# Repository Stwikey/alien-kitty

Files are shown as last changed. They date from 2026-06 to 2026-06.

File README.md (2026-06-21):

# Alien Cat

Screenshot 2026-06-15 at 9 47 17 AM

Have you ever wanted a cute little pet on your desk? Now you can with a cute little cat from outer space. You can pet it by pushing its head down and it'll purr using a vibration motor! Using a rotary encoder you can turn its head around, be careful you don't wanna turn a full 360 or else the cat might start to feel uncomfortable. It's eyes change when you pet it using an LCD.



# How its made
With a 16x2 LCD for its eyes, a vibration motor for purring, an arduino UNO R3 for the brains, and a rotary encoder to turn its head and act as a button. The rest is 3D printed, 4 screws to hold the LCD in place, everything else is either a snap connection or attached when printing. 

# How to use
Alien Cat is easy to use! Leave it on your desk and if you want you can pet it. It's to put simply a desk decoration. You can turn its head around, or press down on its head and it will respond! Twist its head too much and it might get dizzy, but if you pet it (push down) it'll become happy and start purring! 

# Why it was made?
Why not? We looked around and realized our desks are super messy, why not add more to the mess and have a little desk pet. The alien cat design was just a random idea! It was also a good excuse to use components that we haven't used before and to design something that looks cute. 

# Schematic 


# How to assemble
1. The star
   The star comes in two pieces, the "lid" and the star itself. The lid of the star is a thin piece of plastic that should go on the bottom (contrary to the name!). Place your Arduino UNO R3, and batteries on top and then place the star on top.

   Screenshot 2026-06-14 at 11 30 19 PM

   Screenshot 2026-06-14 at 11 28 06 PM

2. The body
   Here it gets a little more difficult! Place the vibration motor and rotary encoder in their respective spots on the top of the body. The vibration motor should fit in the cut out circle spot while the rotary encoder sits in the middle. Connect the wiring for the vibration motor and the rotary encoder by threading the wires through the body. Then you can connect them via the hole in the star and hole at the base of the cat!

   The body is in two pieces, you can put them together after assembling the electronics with adhesive! 

   Screenshot 2026-06-14 at 11 33 17 PM

4. The head
   Another tricky part! Screw in the LCD in the respective slot! The LCD should face outwards and pointing at the hollow holes in the cat face. The head is similar to the body and is in two pieces, you can put them together after assembling the electronics with adhesive! 

   Screenshot 2026-06-14 at 11 35 51 PM

   There is a slot at the base of the cat head to thread wires through. After you are done you can place the cat head direction on top of the rotary encoder.     At the bottom of the cat head there is a spot for it, align it with the grooves for a nice fit.

5. firmware

connect your device to the arduino through a USB cable and run the code on Arduino IDE!

once everything has been placed you now have a alien desktop kitty! push on its head to activate the rotary encoder switch for head pads, twist its head for it to change expressions on the lcd eyes and listen to it purr through the vibration motor
  
Optional steps:

Feel free to sand, prime, and paint the alien kitty. This doesn't serve any functional purpose and is purely cosmetic. 

# BOM 
| | Product Description | | Qty | Unit Price (CAD) | Total (CAD) | Product Link |
|---|---|---|-----|---|---|---|
| | Arduino Uno R3 | | 1 | 5.36 | 5.36 | https://www.aliexpress.com/item/1005009463538789.html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 |
| | LCD 16 x 2 | | 1 | 2.23 | 2.23 | https://www.aliexpress.com/item/1005011609490073.html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 |
| | AA 1.5V Battery | | 4 | 0.395 | 1.58 | https://www.aliexpress.com/item/1005011987720458.html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 |
| | 220 Ω Resistor | | 10  | 0.087 | 0.87 | https://www.aliexpress.com/item/1005007643210127.html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 |
| | 10 Ω Resistor | | 10  | 0.087 | 0.87 | https://www.aliexpress.com/item/1005007643210127.html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 |
| | Vibration Motor 10mm x 2mm | | 1 | 1.28 | 1.28 | https://www.aliexpress.com/item/1005006821274949.html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 |
| | Ec11 Rotary Encoder | | 2 | 2.305 | 4.61 | https://www.aliexpress.com/item/1005006056166298.html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 |
| | 1000 Ω Resistor | | 10  | 0.087 | 1.56 | https://www.aliexpress.com/item/1005007643210127.html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 |
| | NPN Transistor (PN2222) | | 50  | 0.0312 | 1.47 | https://www.aliexpress.com/item/1005009835608932.html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 |
| | Adhesive | | 1 | 0.96 | 0.96 | https://www.aliexpress.com/item/1005005081659956.html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 |
| | M3 Heat Inserts | | 50  | 0.0738 | 3.69 | https://www.aliexpress.com/item/1005008666672949.html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 |
| | Sandpaper | | 15  | 0.08066666667 | 1.21 | https://www.aliexpress.com/item/1005012104535956.html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 |
| | Paint | | 24  | 0.175 | 4.2 | https://www.aliexpress.com/item/1005005567785602.html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 |
| | Primer | | 1 | 17.26 | 17.26 | https://www.aliexpress.com/item/1005012483471322.html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 |
| | Top Coat | | 1 | 13.88 | 13.88 | https://www.amazon.ca/Rust-Oleum-Painters-Touch-Ultra-Semi-Gloss/dp/B081FMDXRY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 |
| | M3 x 3mm Screws | | 10  | 0.112 | 1.12 | https://www.moddiy.com/products/1271/M3.0-x-3mm-Black-Screws-CM3X3-5.0.html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 |
| | 3D Printing | | 1 | 33.42 | 33.42 | https://jlc3dp.com/3d-printing-quote |
| | 9V battery | | 1 | 3.97 | 3.97 | https://www.walmart.ca/en/ip/Great-Value-9-V-6LR61-Alkaline-Battery-1-Pack-5-year-storage-life/6000196063059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 |
| | 4x AA Battery pack | | 1 | 2.82 | 2.82 | https://www.aliexpress.com/item/1005004197639879.html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 |
| | Snap cable connector | | 10  | 0.305 | 3.05 | https://www.aliexpress.com/item/32874851624.html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 |
| Total | | | | 77.82366667 | 95.57 | |

# Credits

Useful websites that helped make this possible:

https://docs.arduino.cc/learn/electronics/lcd-displays/ 

https://chareditor.com/

https://www.build-electronic-circuits.com/arduino-rotary-encoder/

Electronic CAD models used:

[Arduino UNO](https://www.printables.com/model/358867-arduino-uno-3d-model-stp/files) By: Ludvig Broomé

[LCD 16x2](https://www.printables.com/model/1235460-1602a-display-model) By: Даниил Неважно

[Rotary Encoder](https://grabcad.com/library/ec11-rotary-encoder-with-switch-1) By: Anthony Berkow

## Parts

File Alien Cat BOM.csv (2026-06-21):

 | Product Description | Qty | Unit Price (CAD) | Total (CAD) | Product Link
 | Arduino Uno R3 | 1 | 5.36 | 5.36 | https://www.aliexpress.com/item/1005009463538789.html?curPageLogUid=8Lz2kQZ5MYqX
 | LCD 16 x 2 | 1 | 2.23 | 2.23 | https://www.aliexpress.com/item/1005011609490073.html?curPageLogUid=dKYXFKWoafUJ
 | AA 1.5V Battery | 4 | 0.395 | 1.58 | https://www.aliexpress.com/item/1005011987720458.html?curPageLogUid=UbjYgcGQ235k
 | 220 Ω Resistor | 10 | 0.087 | 0.87 | https://www.aliexpress.com/item/1005007643210127.html?curPageLogUid=VnNRhm3IwEaL
 | 10 Ω Resistor | 10 | 0.087 | 0.87 | https://www.aliexpress.com/item/1005007643210127.html?curPageLogUid=VnNRhm3IwEaL
 | Vibration Motor 10mm x 2mm | 1 | 1.28 | 1.28 | https://www.aliexpress.com/item/1005006821274949.html?curPageLogUid=SWakAp59MF29
 | Ec11 Rotary Encoder | 2 | 2.305 | 4.61 | https://www.aliexpress.com/item/1005006056166298.html?curPageLogUid=ISHhlWvBhcbk
 | 1000 Ω Resistor | 10 | 0.087 | 1.56 | https://www.aliexpress.com/item/1005007643210127.html?curPageLogUid=VnNRhm3IwEaL
 | NPN Transistor (PN2222) | 50 | 0.0312 | 1.47 | https://www.aliexpress.com/item/1005009835608932.html?curPageLogUid=4sKOKjuxiQIJ
 | Adhesive | 1 | 0.96 | 0.96 | https://www.aliexpress.com/item/1005005081659956.html?curPageLogUid=uRxGl5EcOYwN
 | M3 Heat Inserts | 50 | 0.0738 | 3.69 | https://www.aliexpress.com/item/1005008666672949.html?curPageLogUid=6IFDnkdYh5Zo
 | Sandpaper | 15 | 0.08066666667 | 1.21 | https://www.aliexpress.com/item/1005012104535956.html?curPageLogUid=LhhxDotHYsMa
 | Paint | 24 | 0.175 | 4.2 | https://www.aliexpress.com/item/1005005567785602.html?curPageLogUid=GT1ATayB9QuS
 | Primer | 1 | 17.26 | 17.26 | https://www.aliexpress.com/item/1005012483471322.html?curPageLogUid=OXpnUWbMSVy4
 | Top Coat | 1 | 13.88 | 13.88 | https://www.amazon.ca/Rust-Oleum-Painters-Touch-Ultra-Semi-Gloss/dp/B081FMDXRY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
 | M3 x 3mm Screws | 10 | 0.112 | 1.12 | https://www.moddiy.com/products/1271/M3.0-x-3mm-Black-Screws-CM3X3-5.0.html
 | 3D Printing | 1 | 33.42 | 33.42 | https://jlc3dp.com/3d-printing-quote
 | 9V battery | 1 | 3.97 | 3.97 | https://www.walmart.ca/en/ip/Great-Value-9-V-6LR61-Alkaline-Battery-1-Pack-5-year-storage-life/6000196063059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
 | 4x AA Battery pack | 1 | 2.82 | 2.82 | https://www.aliexpress.com/item/1005004197639879.html?curPageLogUid=ckLS0CoZgpTw
 | Snap cable connector | 10 | 0.305 | 3.05 | https://www.aliexpress.com/item/32874851624.html?curPageLogUid=SwmAeShmx63n
Total |  |  | 77.82366667 | 95.57

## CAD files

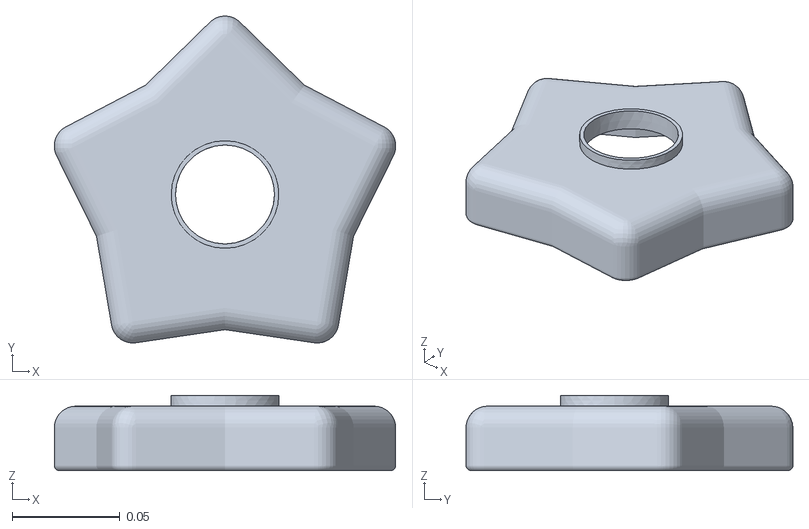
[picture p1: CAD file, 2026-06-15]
CAD/STL Files/starcase.stl
0.159 x 0.152 x 0.035

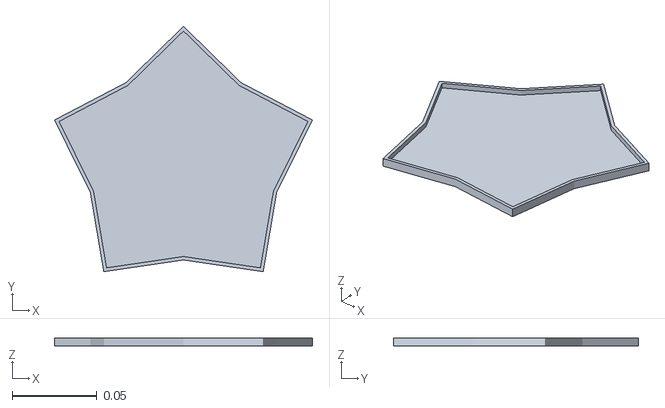
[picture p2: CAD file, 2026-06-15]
CAD/STL Files/starlid.stl
0.152 x 0.145 x 0.005

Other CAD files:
CAD/F3D Files/starcase.f3d
CAD/F3D Files/starlid.f3d

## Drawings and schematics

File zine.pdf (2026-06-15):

# The Alien Cat a companion for your desk

v 1.0

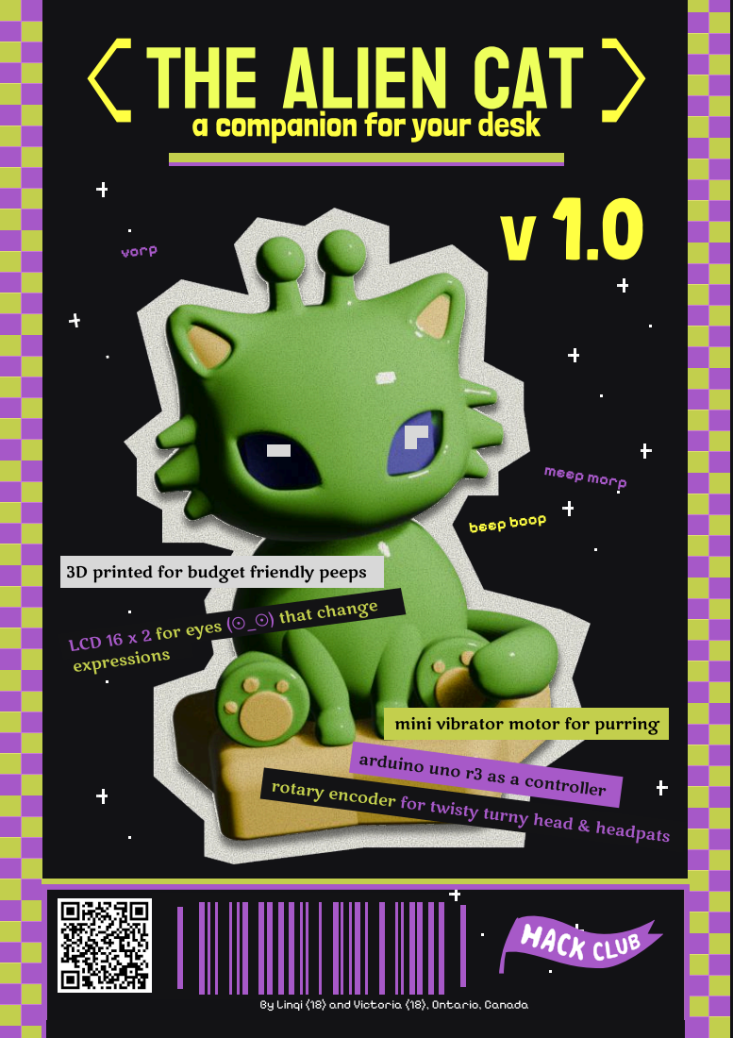
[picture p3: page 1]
vorp; meep morp; beep boop; expressions

3D printed for budget friendly peeps

LCD 16 x 2 for eyes (⊙_⊙) that change

mini vibrator motor for purring

arduino uno r3 as a controller

rotary encoder for twisty turny head & headpats

By Linqi (18) and Victoria (18), Ontario, Canada

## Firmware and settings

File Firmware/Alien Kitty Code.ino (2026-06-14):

// C++ code
//
#include <LiquidCrystal.h>
LiquidCrystal lcd(12, 11, 5, 4, 3, 2);

// rotary encoder
const int encoderPinA = 9;
const int encoderPinB = 10;
const int buttonPin = 7;

int encoderPos = 0;
int pinALastState;
int pinAState;
int death = 0;

const int rotationlimit = 90;


// Face components 
// Default Face
byte default1x14[] = { B11111, B11111, B11111, B11111, B11111, B11111, B11110, B11110 };
byte default0x1[] = { B01111, B01111, B11111, B11111, B11111, B11111, B11111, B11111 };
byte default0x2[] = { B11110, B11110, B11111, B11111, B11111, B11111, B11111, B11111 };
byte default0x13[] = { B01111, B01111, B11111, B11111, B11111, B11111, B11111, B11111 };
byte default0x14[] = { B11110, B11110, B11111, B11111, B11111, B11111, B11111, B11111 };
byte default1x1[] = { B11111, B11111, B11111, B11111, B11111, B11111, B01111, B01111 };
byte default1x2[] = { B11111, B11111, B11111, B11111, B11111, B11111, B11110, B11110 };
byte default1x13[] = { B11111, B11111, B11111, B11111, B11111, B11111, B01111, B01111 };


void defaultface(){
  lcd.createChar(0, default1x14);
  lcd.createChar(1, default0x1);
  lcd.createChar(2, default0x2);
  lcd.createChar(3, default0x13);
  lcd.createChar(4, default0x14);
  lcd.createChar(5, default1x1);
  lcd.createChar(6, default1x2);
  lcd.createChar(7, default1x13);
  
  lcd.setCursor(14, 1);
  lcd.write(byte(0));
  
  lcd.setCursor(1, 0);
  lcd.write(byte(1));
  
  lcd.setCursor(2, 0);
  lcd.write(byte(2));
  
  lcd.setCursor(13, 0);
  lcd.write(byte(3));
  
  lcd.setCursor(14, 0);
  lcd.write(byte(4));
  
  lcd.setCursor(1, 1);
  lcd.write(byte(5));
  
  lcd.setCursor(2, 1);
  lcd.write(byte(6));
  
  lcd.setCursor(13, 1);
  lcd.write(byte(7));
}

// Happy face
byte happy0x1[] = { B00100, B00110, B00111, B00011, B00001, B00000, B00000, B00000 };
byte happy0x2[] = { B00000, B00000, B00000, B10000, B11000, B11100, B01110, B00110 };
byte happy0x14[] = { B00000, B00000, B00001, B00011, B00111, B01110, B11100, B11000 };
byte happy0x15[] = { B01000, B11000, B11000, B10000, B00000, B00000, B00000, B00000 };
byte happy1x1[] = { B00000, B00000, B00000, B00001, B00011, B00111, B00110, B00100 };
byte happy1x2[] = { B00110, B01110, B11100, B11000, B10000, B00000, B00000, B00000 };
byte happy1x14[] = { B11000, B11100, B01110, B00111, B00011, B00001, B00000, B00000 };
byte happy1x15[] = { B00000, B00000, B00000, B00000, B10000, B11000, B11000, B01000 };

void happyface(){
  lcd.createChar(0, happy0x1);
  lcd.createChar(1, happy0x2);
  lcd.createChar(2, happy0x14);
  lcd.createChar(3, happy0x15);
  lcd.createChar(4, happy1x1);
  lcd.createChar(5, happy1x2);
  lcd.createChar(6, happy1x14);
  lcd.createChar(7, happy1x15);
  
  lcd.setCursor(1, 0);
  lcd.write(byte(0));
  lcd.setCursor(2, 0);
  lcd.write(byte(1));
  lcd.setCursor(14, 0);
  lcd.write(byte(2));
  lcd.setCursor(15, 0);
  lcd.write(byte(3));
  lcd.setCursor(1, 1);
  lcd.write(byte(4));
  lcd.setCursor(2, 1);
  lcd.write(byte(5));
  lcd.setCursor(14, 1);
  lcd.write(byte(6));
  lcd.setCursor(15, 1);
  lcd.write(byte(7));
  
}

// Dead face 
byte dead0x11[] = { B00100, B00110, B00111, B00011, B00001, B00000, B00000, B00000 };
byte dead0x1[] = { B00100, B00110, B00111, B00011, B00001, B00000, B00000, B00000 };
byte dead0x2[] = { B00000, B00000, B00000, B10000, B11000, B11100, B01110, B00111 };
byte dead0x3[] = { B00000, B00000, B00000, B00001, B00011, B00111, B01110, B11100 };
byte dead0x4[] = { B00100, B01100, B11100, B11000, B10000, B00000, B00000, B00000 };
byte dead0x12[] = { B00000, B00000, B00000, B10000, B11000, B11100, B01110, B00111 };
byte dead0x13[] = { B00000, B00000, B00000, B00001, B00011, B00111, B01110, B11100 };
byte dead0x14[] = { B00100, B01100, B11100, B11000, B10000, B00000, B00000, B00000 };
byte dead1x1[] = { B00000, B00000, B00000, B00000, B00001, B00011, B00111, B00110 };
byte dead1x2[] = { B00011, B00111, B01110, B11100, B11000, B10000, B00000, B00000 };
byte dead1x3[] = { B11000, B11100, B01110, B00111, B00011, B00001, B00000, B00000 };
byte dead1x4[] = { B00000, B00000, B00000, B00000, B10000, B11000, B11100, B01100 };
byte dead1x11[] = { B00000, B00000, B00000, B00000, B00001, B00011, B00111, B00110 };
byte dead1x12[] = { B00011, B00111, B01110, B11100, B11000, B10000, B00000, B00000 };
byte dead1x13[] = { B11000, B11100, B01110, B00111, B00011, B00001, B00000, B00000 };
byte dead1x14[] = { B00000, B00000, B00000, B00000, B10000, B11000, B11100, B01100 };

void deadface(){
  lcd.createChar(0, dead0x11);
  lcd.setCursor(11, 0);
  lcd.write(byte(0));
  
  lcd.createChar(1, dead0x1);
  lcd.setCursor(1, 0);
  lcd.write(byte(1));
  
  lcd.createChar(2, dead0x2);
  lcd.setCursor(2, 0);
  lcd.write(byte(2));
  
  lcd.createChar(3, dead0x3);
  lcd.setCursor(3, 0);
  lcd.write(byte(3));
  
  lcd.createChar(4, dead0x4);
  lcd.setCursor(4, 0);
  lcd.write(byte(4));
  
  lcd.createChar(5, dead0x12);
  lcd.setCursor(12, 0);
  lcd.write(byte(5));
  
  lcd.createChar(6, dead0x13);
  lcd.setCursor(13, 0);
  lcd.write(byte(6));
  
  lcd.createChar(7, dead0x14);
  lcd.setCursor(14, 0);
  lcd.write(byte(7));
  
  lcd.createChar(8, dead1x1);
  lcd.setCursor(1, 1);
  lcd.write(byte(8));
  
  lcd.createChar(9, dead1x2);
  lcd.setCursor(2, 1);
  lcd.write(byte(9));
  
  lcd.createChar(10, dead1x3);
  lcd.setCursor(3, 1);
  lcd.write(byte(10));
  
  lcd.createChar(11, dead1x4);
  lcd.setCursor(4, 1);
  lcd.write(byte(11));
  
  lcd.createChar(12, dead1x11);
  lcd.setCursor(11, 1);
  lcd.write(byte(12));
  
  lcd.createChar(13, dead1x12);
  lcd.setCursor(12, 1);
  lcd.write(byte(13));
  
  lcd.createChar(14, dead1x13);
  lcd.setCursor(13, 1);
  lcd.write(byte(14));
  
  lcd.createChar(15, dead1x14);
  lcd.setCursor(14, 1);
  lcd.write(byte(15));
}

void setup()
{ 
  pinMode(6, OUTPUT);
  analogWrite(6, 150);
  
  pinMode(buttonPin, INPUT);
  pinMode(encoderPinA, INPUT);
  pinMode(encoderPinB, INPUT);
  lcd.begin(16,2);
 
  defaultface();
  pinALastState = digitalRead(encoderPinA);
}


void loop()
{
  delay(10); // Delay a little bit to improve simulation performance
  pinAState = digitalRead(encoderPinA);
  if (pinAState != pinALastState){
    if (digitalRead(encoderPinB) != pinAState) {
      encoderPos ++;
    }
    else{
      encoderPos --;
    }
  }
  if (abs(encoderPos) >= rotationlimit){
      if (death != 1) { 
        lcd.clear();
        deadface();
        death = 1;
      }
    }
    else {
      if (death != 0) { 
        lcd.clear();
        defaultface();
        death = 0;
      }
    }
  if (digitalRead(buttonPin) == HIGH) {
    lcd.clear();
    analogWrite(9,250);
    happyface();
    delay(1000);
    lcd.clear();
    analogWrite(9,0);
    
    if (abs(encoderPos) >= rotationlimit) {
      deadface();
      death = 1;
    }
    else {
      defaultface();
      death = 0;
    }
  }
  pinALastState = pinAState;
}

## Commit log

2026-06-14 Uploaded wiring schematic
    [alienkitty.kicad_sch]
2026-06-14 Uploaded full assembly
2026-06-15 added BOM to readme
2026-06-15 fixed up source files
    [starcase.stl, starlid.stl]
2026-06-15 update files
    [Alien Cat Assembly.step, Star Lid.f3z, Star Lid.step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]
2026-06-15 Update README with firmware connection instructions
    Added instructions for connecting the device and running the firmware.
2026-06-15 update BOM
    [Alien Cat BOM.csv]
2026-06-18 Added STL files
    [starcase.stl, starlid.stl]
2026-06-18 Upload f3d files
    [Alien Cat Assembly.step, headback.step, headfront.step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]
